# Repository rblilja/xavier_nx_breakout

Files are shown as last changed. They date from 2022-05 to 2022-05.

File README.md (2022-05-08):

# xavier_nx_breakout
Header breakout for NVIDIA Jetson Xavier NX Development Kit.

This breakout board overcomes the limitation of the 2uA maximum output current (per pin) of the TXB0108 8-Bit Bidirectional Voltage-Level Translators used for the GPIOs of the J12 header.

The breakout provides the following:

* UART1_TX and UART1_RTS buffered with non-inverting Schmitt triggers.
* PWM capable GPIO07, GPIO12 and GPIO13 buffered with non-inverting Schmitt triggers.
* Pixhawk compatible interface (JST-GH 6-pin 1.25 mm pitch) provided for UART1.
* Stemma QT / Qwiic (JST-SH 4-pin 1.0 mm pitch) compatible interface provided for I2C0.
* Pixhawk compatible interface (JST-GH 4-pin 1.25 mm pitch) provided for I2C1.

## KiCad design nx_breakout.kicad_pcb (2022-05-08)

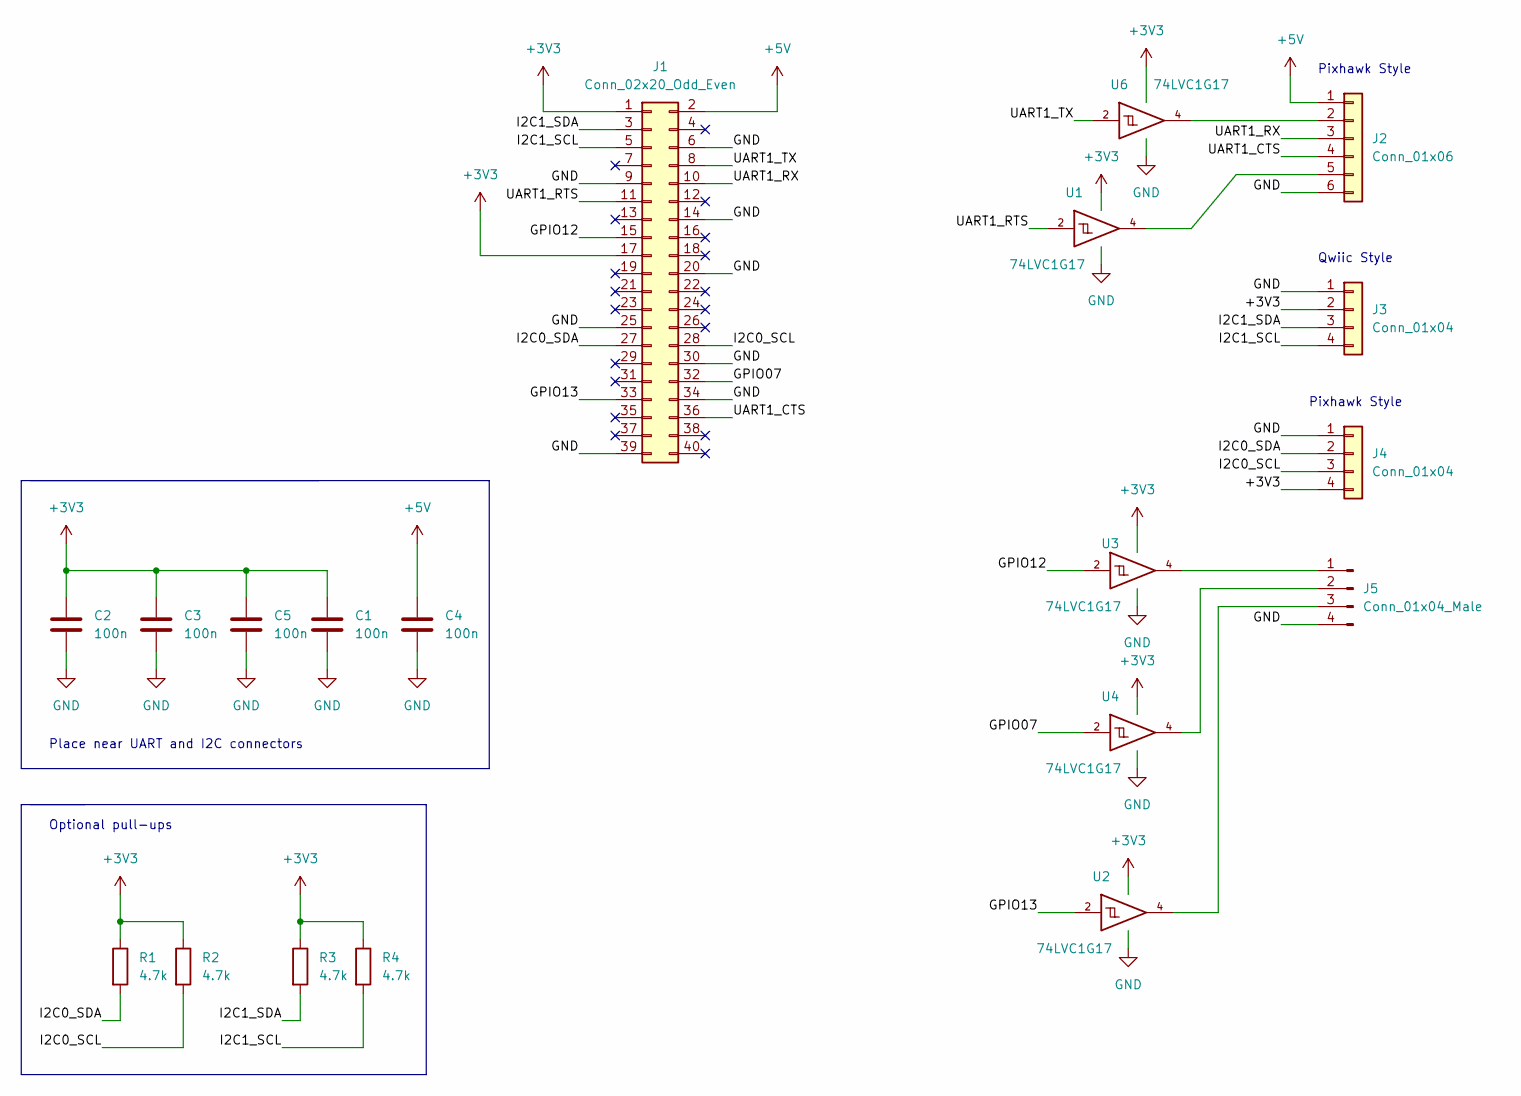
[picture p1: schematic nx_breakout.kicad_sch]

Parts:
C1, C2, C3, C4, C5: 100n; C_0603_1608Metric_Pad1.08x0.95mm_HandSolder
J1: Conn_02x20_Odd_Even; PinSocket_2x20_P2.54mm_Horizontal
J2: Conn_01x06; JST_GH_BM06B-GHS-TBT_1x06-1MP_P1.25mm_Vertical
J3: Conn_01x04; JST_SH_BM04B-SRSS-TB_1x04-1MP_P1.00mm_Vertical
J4: Conn_01x04; JST_GH_BM04B-GHS-TBT_1x04-1MP_P1.25mm_Vertical
J5: Conn_01x04_Male; PinHeader_1x04_P2.54mm_Vertical
R1, R2, R3, R4: 4.7k; R_0603_1608Metric_Pad0.98x0.95mm_HandSolder
U1, U2, U3, U4, U6: 74LVC1G17; SOT-23-5_HandSoldering

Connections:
+3V3: C1.1, C2.1, C3.1, C5.1, J1.1, J1.17, J3.2, J4.4, R1.1, R2.1, R3.1, R4.1, U1.5 (VCC), U2.5 (VCC), U3.5 (VCC), U4.5 (VCC), U6.5 (VCC)
+5V: C4.1, J1.2, J2.1
/GPIO07: J1.32, U4.2
/GPIO12: J1.15, U3.2
/GPIO13: J1.33, U2.2
/I2C0_SCL: J1.28, J4.3, R2.2
/I2C0_SDA: J1.27, J4.2, R1.2
/I2C1_SCL: J1.5, J3.4, R4.2
/I2C1_SDA: J1.3, J3.3, R3.2
/UART1_CTS: J1.36, J2.4
/UART1_RTS: J1.11, U1.2
/UART1_RX: J1.10, J2.3
/UART1_TX: J1.8, U6.2
GND: C1.2, C2.2, C3.2, C4.2, C5.2, J1.6, J1.9, J1.14, J1.20, J1.25, J1.30, J1.34, J1.39, J2.6, J3.1, J4.1, J5.4, U1.3 (GND), U2.3 (GND), U3.3 (GND), U4.3 (GND), U6.3 (GND)
unnamed: J2.5, U1.4
unnamed: J5.1, U3.4
unnamed: J5.2, U4.4
unnamed: J5.3, U2.4
unnamed: J2.2, U6.4

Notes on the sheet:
Place near UART and I2C connectors
Pixhawk Style
Qwiic Style
Optional pull-ups

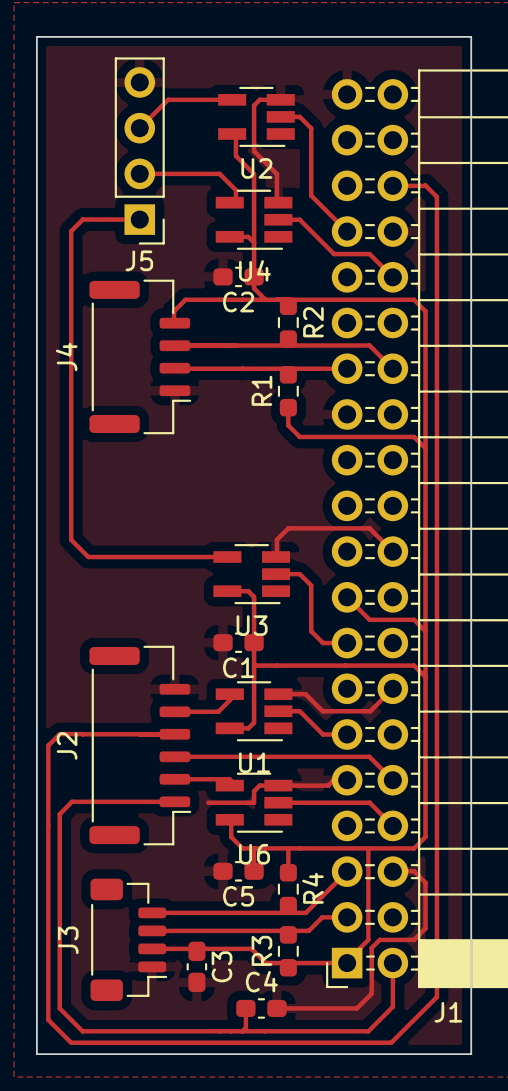
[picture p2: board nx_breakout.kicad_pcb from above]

Board: 2 copper layers, 24.1 x 56.5 mm, 19 parts (0 on the bottom side), 19 nets.
